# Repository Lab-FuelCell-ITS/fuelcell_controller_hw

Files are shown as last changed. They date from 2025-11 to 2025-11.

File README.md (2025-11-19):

# Fuel Cell Controller — Hardware

This repository contains the KiCad schematic and PCB hardware design for the Fuel Cell Controller developed by **Lab-FuelCell-ITS**. The project includes complete KiCad source files, symbol/footprint libraries, and backups used for designing, modifying, and fabricating the controller board.

<!-- <img width="1049" height="713" alt="{BA82DBBF-16C6-43F1-AAF5-F1074114E6D2}" src="https://github.com/user-attachments/assets/8fef73a0-f4a1-47a8-a998-3048bcc98810" />
<img width="1056" height="700" alt="{CD6223DB-963B-4A11-8DCC-30DFFEBB6A86}" src="https://github.com/user-attachments/assets/9b73dac4-e640-4459-982e-8afceb8b78d7" /> -->
<div style="display: flex; justify-content: center; gap: 10px;">
  
  
</div>

---

## Features

- Full KiCad project (schematics + PCB layout)
- Custom symbol and footprint libraries
- Backup snapshots for restoration
- Ready for Gerber and BOM generation
- Structured for collaboration and long-term maintenance

---

## Repository Contents

- `fuelcell.kicad_pro` — main KiCad project file  
- `fuelcell.kicad_sch` — schematic  
- `fuelcell.kicad_pcb` — PCB layout  
- `fuel_cell_lib.kicad_sym` — symbol library  
- `fuel_cell_foot.pretty/` — footprint library  
- `fuelcell-backups/` — automatic KiCad backups  
- KiCad metadata: `fp-lib-table`, `sym-lib-table`, `fp-info-cache`, etc.

---

## Notes for next update
- CAN label flipped
- added more space between DC-DC connector
- Nextion should supplied from 5v

--- 

## Requirements

- **KiCad (v9 or newer)**  
  Older versions may open the project but can cause compatibility issues.
  
---

## BOM
[BOM](https://docs.google.com/spreadsheets/d/1h5o9iBbPZtMF7gXZkPm5TLBS_tpg8lyO8AkKIXZHr1Q/edit?gid=0#gid=0)

list belanja
---

## How to Open the Project

1. Clone the repository:
   ```bash
   git clone https://github.com/Lab-FuelCell-ITS/fuelcell_controller_hw.git
   cd fuelcell_controller_hw

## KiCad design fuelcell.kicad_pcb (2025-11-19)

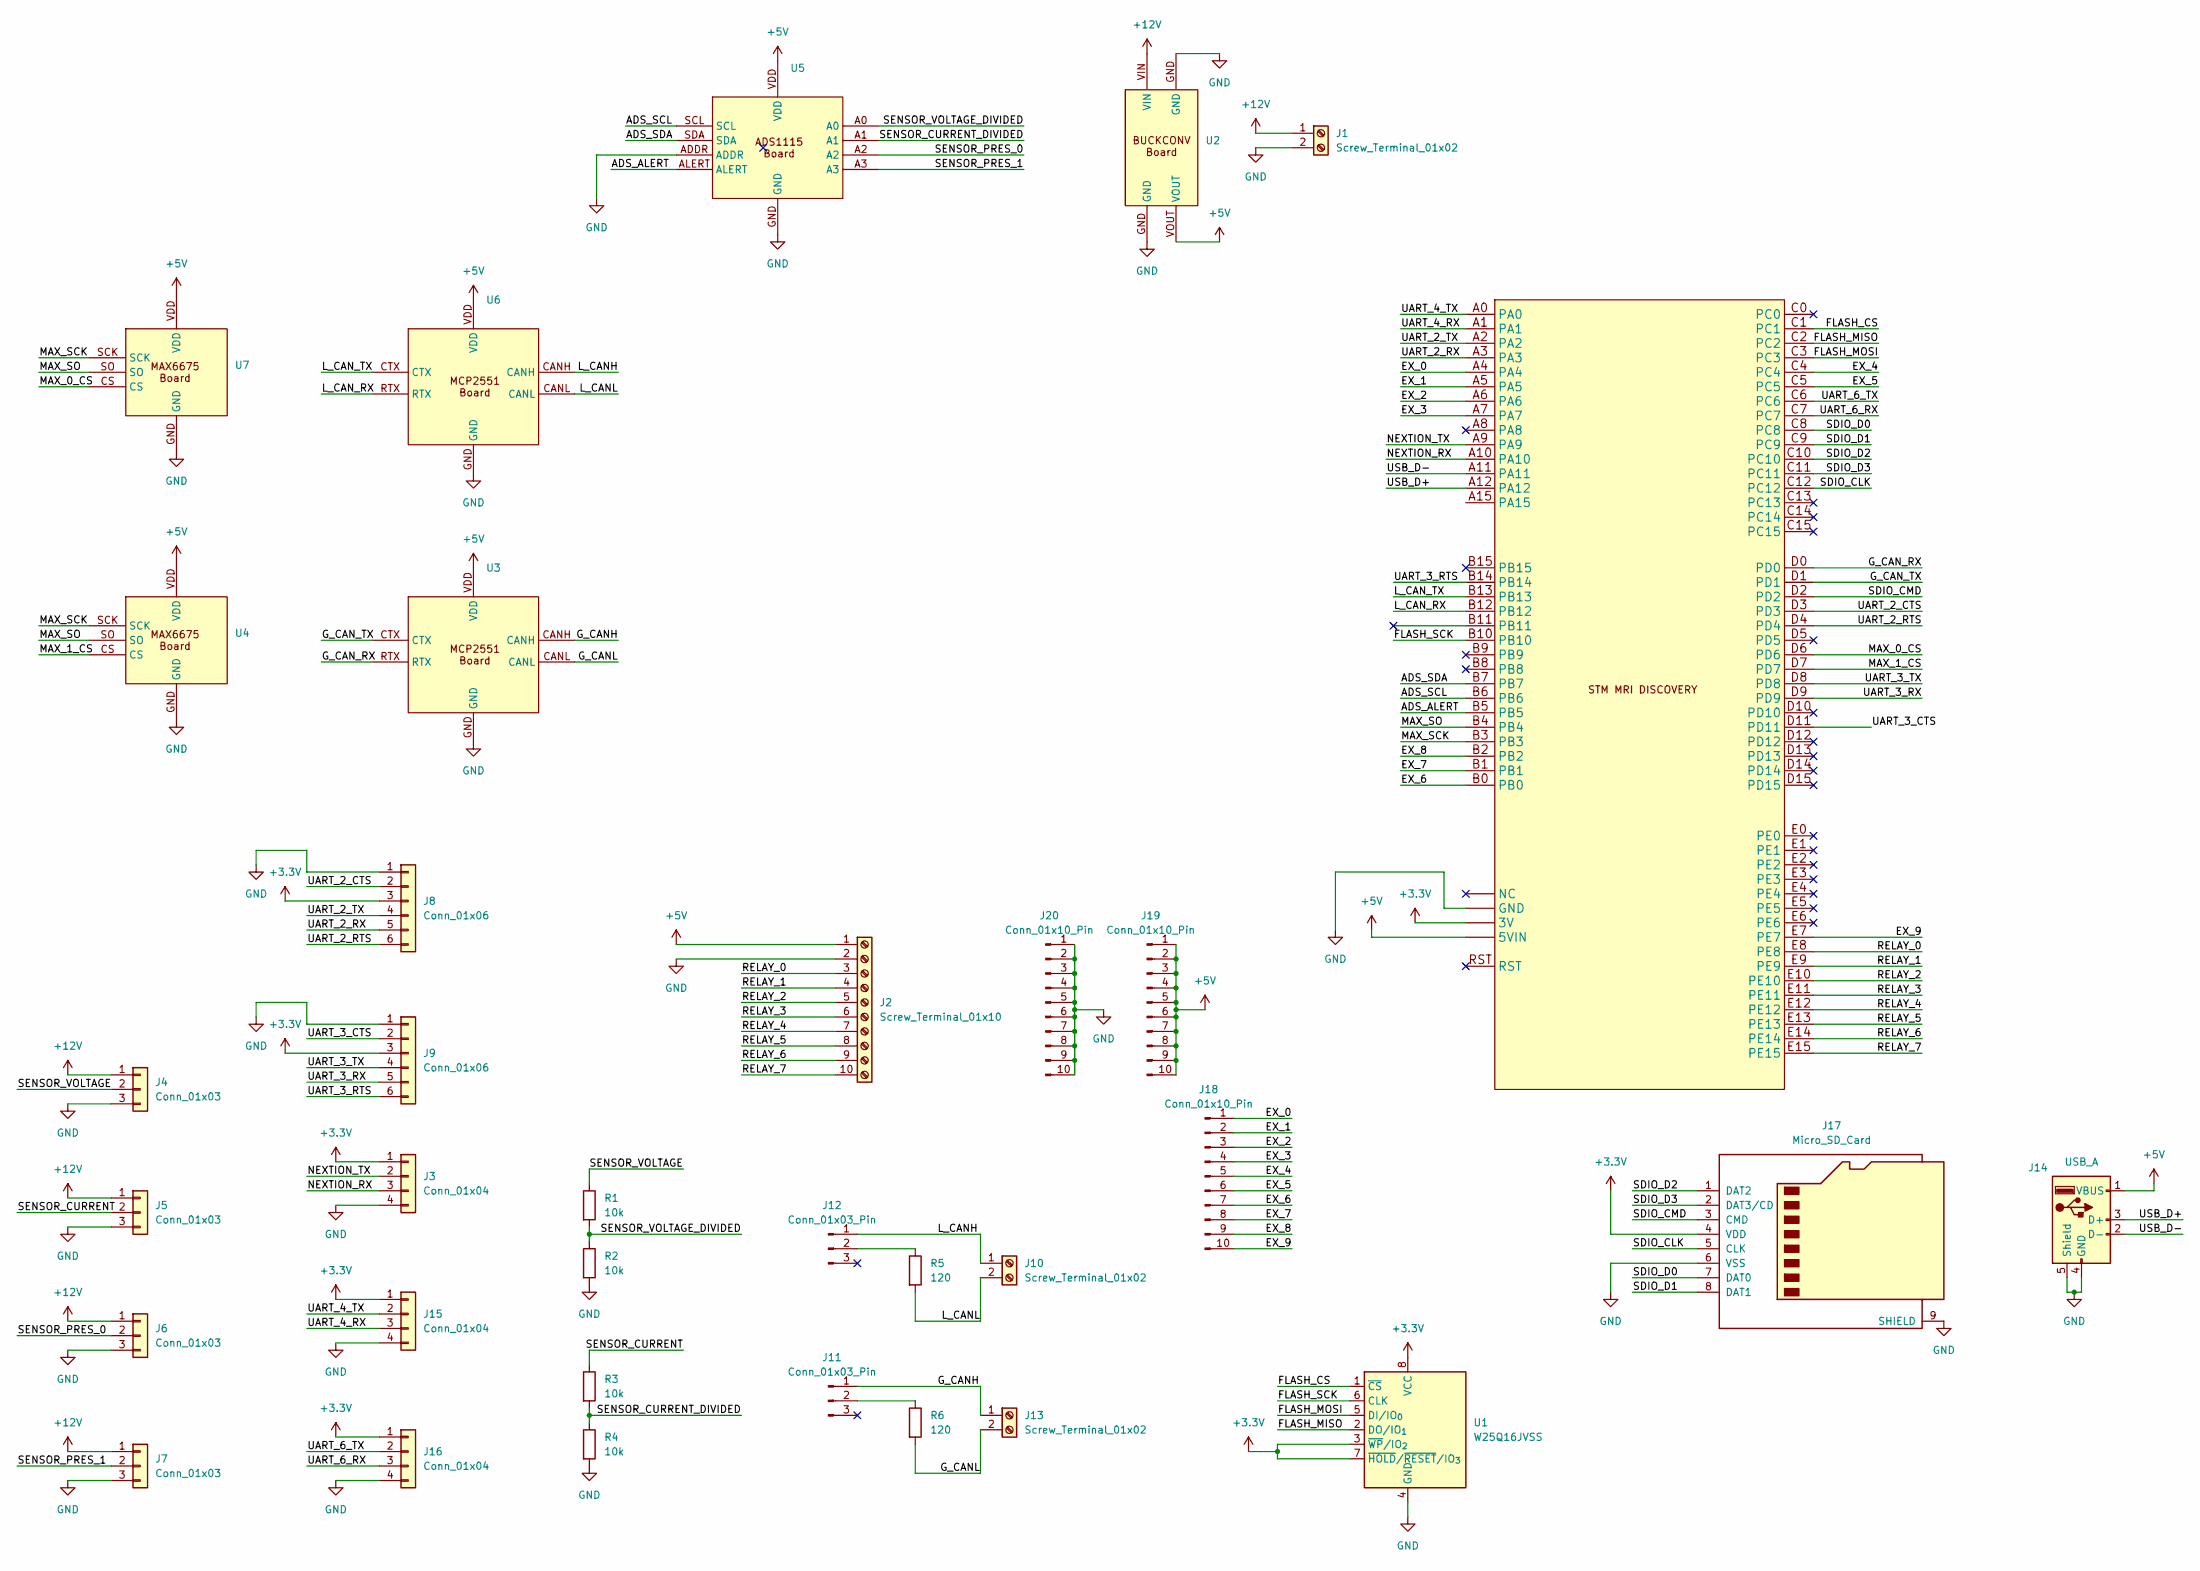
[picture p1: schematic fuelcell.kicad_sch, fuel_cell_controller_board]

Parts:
J1, J10, J13: Screw_Terminal_01x02; TerminalBlock_Phoenix_MKDS-1,5-2-5.08_1x02_P5.08mm_Horizont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
J2: Screw_Terminal_01x10; TerminalBlock_Phoenix_MKDS-3-10-5.08_1x10_P5.08mm_Horizontal
J3, J15, J16: Conn_01x04; PinHeader_1x04_P2.54mm_Vertical
J4, J5, J6, J7: Conn_01x03; PinHeader_1x03_P2.54mm_Vertical
J8, J9: Conn_01x06; PinHeader_1x06_P2.54mm_Vertical
J11, J12: Conn_01x03_Pin; PinHeader_1x03_P2.54mm_Vertical
J14: USB_A; USB_A_Molex_67643_Horizontal
J17: Micro_SD_Card; microSD_HC_Molex_47219-2001
J18, J19, J20: Conn_01x10_Pin; PinHeader_1x10_P2.54mm_Vertical
R1, R2, R3, R4: 10k; R_Axial_DIN0207_L6.3mm_D2.5mm_P10.16mm_Horizontal
R5, R6: 120; R_Axial_DIN0207_L6.3mm_D2.5mm_P10.16mm_Horizontal
U1: W25Q16JVSS; SOIC-8_5.3x5.3mm_P1.27mm
U2: Buck_Board
U3, U6: MCP2551_Board
U4, U7: MAX6675_Board
U5: ADS1115_Board
U8: STM32F4HEAD

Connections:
+3.3V: J3.1, J8.3, J9.3, J15.1, J16.1, J17.4 (VDD), U1.3 (~WP/IO_{2}), U1.7 (~HOLD/~RESET/IO_{3}), U1.8 (VCC), U8.3V1 (3V), U8.3V2 (3V), U8.3V3 (3V)
+5V: J2.1, J14.1 (VBUS), J19.1, J19.2, J19.3, J19.4, J19.5, J19.6, J19.7, J19.8, J19.9, J19.10, U2.VOUT, U3.VDD, U4.VDD, U5.VDD, U6.VDD, U7.VDD, U8.5V1 (5VIN), U8.5V2 (5VIN)
+12V: J1.1, J4.1, J5.1, J6.1, J7.1, U2.VIN
/ADS_ALERT: U5.ALERT, U8.B5
/ADS_SCL: U5.SCL, U8.B6
/ADS_SDA: U5.SDA, U8.B7
/EX_0: J18.1, U8.A4
/EX_1: J18.2, U8.A5
/EX_2: J18.3, U8.A6
/EX_3: J18.4, U8.A7
/EX_4: J18.5, U8.C4
/EX_5: J18.6, U8.C5
/EX_6: J18.7, U8.B0
/EX_7: J18.8, U8.B1
/EX_8: J18.9, U8.B2
/EX_9: J18.10, U8.E7
/FLASH_CS: U1.1 (~CS), U8.C1
/FLASH_MISO: U1.2 (DO/IO_{1}), U8.C2
/FLASH_MOSI: U1.5 (DI/IO_{0}), U8.C3
/FLASH_SCK: U1.6 (CLK), U8.B10
/G_CANH: J11.1, J13.1, U3.CANH
/G_CANL: J13.2, R6.2, U3.CANL
/G_CAN_RX: U3.RTX, U8.D0
/G_CAN_TX: U3.CTX, U8.D1
/L_CANH: J10.1, J12.1, U6.CANH
/L_CANL: J10.2, R5.2, U6.CANL
/L_CAN_RX: U6.RTX, U8.B12
/L_CAN_TX: U6.CTX, U8.B13
/MAX_0_CS: U7.CS, U8.D6
/MAX_1_CS: U4.CS, U8.D7
/MAX_SCK: U4.SCK, U7.SCK, U8.B3
/MAX_SO: U4.SO, U7.SO, U8.B4
/NEXTION_RX: J3.3, U8.A10
/NEXTION_TX: J3.2, U8.A9
/RELAY_0: J2.3, U8.E8
/RELAY_1: J2.4, U8.E9
/RELAY_2: J2.5, U8.E10
/RELAY_3: J2.6, U8.E11
/RELAY_4: J2.7, U8.E12
/RELAY_5: J2.8, U8.E13
/RELAY_6: J2.9, U8.E14
/RELAY_7: J2.10, U8.E15
/SDIO_CLK: J17.5 (CLK), U8.C12
/SDIO_CMD: J17.3 (CMD), U8.D2
/SDIO_D0: J17.7 (DAT0), U8.C8
/SDIO_D1: J17.8 (DAT1), U8.C9
/SDIO_D2: J17.1 (DAT2), U8.C10
/SDIO_D3: J17.2 (DAT3/CD), U8.C11
/SENSOR_CURRENT: J5.2, R3.1
/SENSOR_CURRENT_DIVIDED: R3.2, R4.1, U5.A1
/SENSOR_PRES_0: J6.2, U5.A2
/SENSOR_PRES_1: J7.2, U5.A3
/SENSOR_VOLTAGE: J4.2, R1.1
/SENSOR_VOLTAGE_DIVIDED: R1.2, R2.1, U5.A0
/UART_2_CTS: J8.2, U8.D3
/UART_2_RTS: J8.6, U8.D4
/UART_2_RX: J8.5, U8.A3
/UART_2_TX: J8.4, U8.A2
/UART_3_CTS: J9.2, U8.D11
/UART_3_RTS: J9.6, U8.B14
/UART_3_RX: J9.5, U8.D9
/UART_3_TX: J9.4, U8.D8
/UART_4_RX: J15.3, U8.A1
/UART_4_TX: J15.2, U8.A0
/UART_6_RX: J16.3, U8.C7
/UART_6_TX: J16.2, U8.C6
/USB_D+: J14.3 (D+), U8.A12
/USB_D-: J14.2 (D-), U8.A11
GND: J1.2, J2.2, J3.4, J4.3, J5.3, J6.3, J7.3, J8.1, J9.1, J14.4 (GND), J14.5 (Shield), J15.4, J16.4, J17.6 (VSS), J17.9 (SHIELD), J20.1, J20.2, J20.3, J20.4, J20.5, J20.6, J20.7, J20.8, J20.9, J20.10, R2.2, R4.2, U1.4 (GND), U2.GND, U3.GND, U4.GND, U5.ADDR, U5.GND, U6.GND, U7.GND, U8.GND1 (GND), U8.GND2 (GND), U8.GND3 (GND)
unnamed: J11.2, R6.1
unnamed: J12.2, R5.1

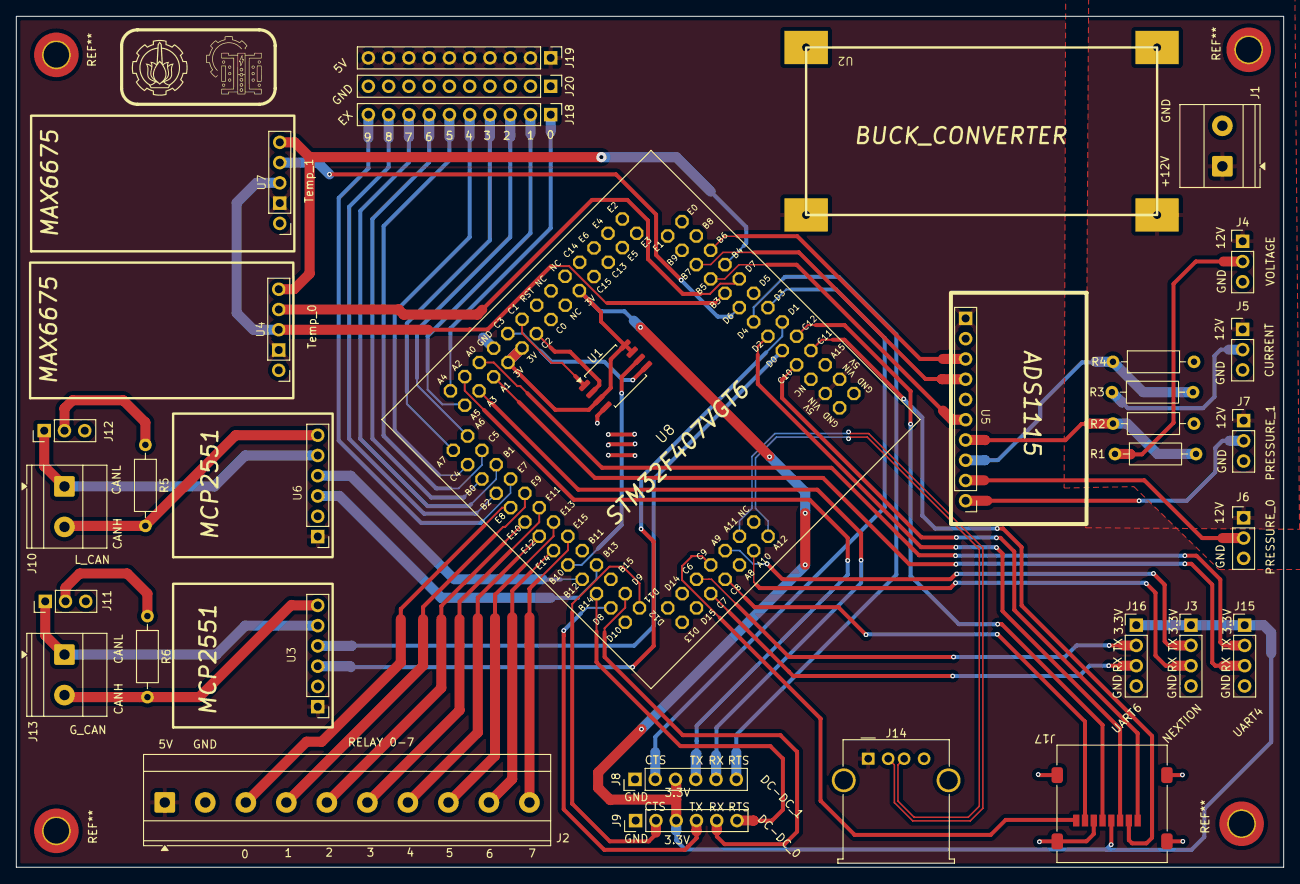
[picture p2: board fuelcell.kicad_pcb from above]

Board: 2 copper layers, 158.9 x 106.7 mm, 34 parts (0 on the bottom side), 71 nets.
